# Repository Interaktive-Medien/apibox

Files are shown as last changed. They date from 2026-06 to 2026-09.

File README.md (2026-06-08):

# API Box — ESP32-C6 Sensor-API

**Modul:** Interaktive Medien 3 an der Fachhochschule Graubünden
**Studiengang:** Multimedia Production · 3. Semester
**Board:** Waveshare ESP32-C6-N8

> Eine wasserdichte IoT-Applikation auf dem ESP32-C6, die als **HTTP-API-Endpunkt**
> fungiert. Angeschlossene Sensoren werden in Echtzeit per HTTP GET abgefragt und als
> **JSON** zurückgegeben — bereit zum Einsammeln und Auswerten über einen längeren Zeitraum.

*[Platz für Bilder / GIFs des fertigen Aufbaus]*

---

## Kurzbeschreibung des Projekts

Die **API Box** ist ein kleiner Webserver auf dem ESP32-C6. Sie verbindet sich mit einem
WLAN und stellt für jeden angeschlossenen Sensor einen eigenen API-Endpunkt bereit.
Ein beliebiger Netzwerkteilnehmer (Browser, JavaScript `fetch()`, PHP `cURL`) ruft einen
Endpunkt auf und erhält den aktuellen Messwert als JSON-String:

```
GET http://192.168.0.42/temperatur

{
  "wert": 22.7,
  "einheit": "°C",
  "datentyp": "float",
  "sensor": "SCD41"
}
```

Werte werden **punktuell** abgefragt (kein dauerhaftes Logging auf dem ESP) — gespeichert
und ausgewertet wird auf der Client-/Serverseite.

Findet der ESP kein bekanntes Netzwerk, startet er ein **Captive Portal** (Access Point
`apibox`) mit einem modernen Formular zur Eingabe der WLAN-Zugangsdaten. Ein **SSD1306
OLED** zeigt jederzeit den Status (Suche / verbunden + IP / Portal-Hinweis).

---

## Setup

### Was benötige ich an Infrastruktur?

* **Waveshare ESP32-C6-N8** + USB-C-Kabel
* **Arduino IDE** (2.x) mit installiertem **ESP32 Arduino Core 3.3.x** (Boardverwalter)
* Das Plugin **[arduino-littlefs-upload](https://github.com/earlephilhower/arduino-littlefs-upload)**
  (zum Hochladen der Website-Dateien)
* Breadboard, Jumperkabel, die unten gelisteten Sensoren
* Ein WLAN-Netzwerk (Heim **oder** Schule/eduroam)

### Benötigte Arduino-Libraries

Über **Library Manager** installieren:

| Library | Zweck |
|---|---|
| `Arduino_JSON` (Arduino) | JSON-Antworten erzeugen |
| `Adafruit SSD1306` (+ GFX, + BusIO) | OLED-Display |
| `Sensirion I2C SCD4x` (+ Sensirion Core) | SCD41: Temperatur, Luftfeuchtigkeit, CO2 |
| `BH1750` (Christopher Laws) | Helligkeit |
| `ICM20948_WE` (Wolfgang Ewald) | Lage / 9DOF |
| `HX711 Arduino Library` (Bogdan Necula) | Gewicht |
| `Adafruit BMP280 Library` (+ Adafruit Unified Sensor) | Luftdruck + Höhe |
| `Adafruit VL53L0X` | Distanz |

`WiFi`, `WebServer`, `DNSServer`, `Preferences`, `Wire`, `LittleFS`, `driver/i2s.h`
sind im ESP32-Core bereits enthalten.

### Komponentenplan

```
                         ┌─────────────────────────────┐
        WLAN  ◀────────▶ │   Waveshare ESP32-C6-N8     │
   (Heim / eduroam)      │   ── mc.ino (Webserver) ──  │
                         └──────────────┬──────────────┘
                                        │
         ┌──────────────────────────────┼───────────────────────────────┐
         │ I2C-Bus (GPIO6 SDA / GPIO7 SCL)                               │
         │   ├─ SSD1306 OLED      → display.h        (Statusanzeige)     │
         │   ├─ SCD41             → temperatur.h / luftfeuchtigkeit.h /  │
         │   │                      co2.h            (/temperatur …)     │
         │   ├─ BH1750            → helligkeit.h     (/helligkeit)       │
         │   ├─ ICM-20948         → lage.h           (/lage)            │
         │   ├─ BMP280            → luftdruck.h / hoehe.h (/luftdruck…)  │
         │   └─ VL53L0X           → distanz.h        (/distanz)          │
         │                                                               │
         │ Digital / Analog / I2S                                        │
         │   ├─ SR602  PIR  GPIO4        → bewegung.h    (/bewegung)     │
         │   ├─ GPS14-B     GPIO11       → magnet.h      (/magnet)       │
         │   ├─ MQ-3        GPIO5 (ADC)  → alkohol.h     (/alkohol)      │
         │   ├─ MQ-2        GPIO0 (ADC)  → rauch.h       (/rauch)        │
         │   ├─ INMP441 I2S GPIO2/13/23  → lautstaerke.h (/lautstaerke)  │
         │   ├─ HX711       GPIO21/22    → gewicht.h     (/gewicht)      │
         │   └─ Taster      GPIO20       → captive_portal.h (Portal)     │
         │                                                               │
         │ Webseite (LittleFS): data/index.html + css + js               │
         └───────────────────────────────────────────────────────────────┘
                                        │
        Client: fetch() (JS)  ◀────────┴────────▶  Server: cURL (PHP)
```

### Verkabelung / Pinbelegung

| ESP32-C6 Pin | Komponente | Hinweis |
|---|---|---|
| **GPIO6 (SDA) / GPIO7 (SCL)** | I2C-Bus: SSD1306, SCD41, BH1750, ICM-20948, BMP280, VL53L0X | gemeinsamer Bus |
| GPIO4 | SR602 PIR (Bewegung) | Input |
| GPIO5 | MQ-3 (Alkohol) | Analog/ADC1, VCC **5V** |
| GPIO0 | MQ-2 (Rauch) | Analog/ADC1, VCC **5V** |
| GPIO11 | GPS14-B (Magnet) | INPUT_PULLUP |
| GPIO20 | Taster (Captive Portal) | INPUT_PULLDOWN |
| GPIO2 / GPIO13 / GPIO23 | INMP441 SCK / SD / WS | I2S, L/R → GND |
| **GPIO21 / GPIO22** | HX711 DT / SCK (Waage) | **siehe Warnung unten** |
| 3.3V / 5V / GND | Versorgung | MQ-Sensoren brauchen 5V |

> ⚠️ **Wichtig — HX711 NICHT auf GPIO6/7!**
> Im ursprünglichen Steckplan lag der HX711 (Waage) auf GPIO6/7 — das ist aber der I2C-Bus.
> Der HX711 ist **kein I2C-Gerät** und würde den Bus (Display + 5 Sensoren) stören.
> Deshalb in dieser Applikation auf **GPIO21 (DT) / GPIO22 (SCK)** verlegt. Bitte die Waage
> entsprechend verdrahten.

> 💡 **Zur Frage I2C-Pull-ups (2.2 kΩ auf SDA/SCL nach 3.3V):** Grundsätzlich sinnvoll,
> **aber** die meisten Breakout-Boards (BH1750, BMP280, SCD41, OLED) haben bereits Pull-ups
> onboard. Hängen viele Module am Bus, summieren sich diese parallel und ziehen den Bus zu
> stark. Empfehlung: **ein einziges** Paar 2.2–4.7 kΩ genügt — nicht pro Sensor. Bei kurzen
> Breadboard-Strecken oft ganz verzichtbar. Treten I2C-Aussetzer auf, ist ein Pull-up-Paar
> der erste Versuch.

### Steckplan

Der Fritzing-Steckplan liegt im Repository (`steckplan.png`). Erstellt mit
[Fritzing](https://fritzing.org). Fritzing-Parts für die Lehrveranstaltung:
[Interaktive-Medien / 15_Intro_Projektdoku](https://github.com/Interaktive-Medien/im_physical_computing/tree/main/15_Intro_Projektdoku).

*(Achtung: Im Steckplan liegt der HX711 noch auf GPIO6/7 — in der Software auf GPIO21/22
korrigiert, siehe Warnung oben.)*

### Umgang mit LittleFS (Website hochladen)

Die Website (HTML/CSS/JS) wird **getrennt vom Code** als Datei-Image hochgeladen:

1. Plugin **arduino-littlefs-upload** installieren (siehe Link oben). Video-Tutorial:
   <https://youtu.be/Qw5mQus-WwA>
2. Die Dateien liegen im Ordner **`mc/data/`** (`index.html`, `css/style.css`, `js/script.js`).
3. In der Arduino IDE: `mc.ino` öffnen → **CMD + SHIFT + P** → **„Upload LittleFS to
   Pico/ESP8266/ESP32"**.
4. Dabei wird der komplette `data/`-Ordner auf den ESP gespiegelt. Alte Dateien auf dem ESP
   werden gelöscht — nicht mehr benötigte Dateien müssen also nicht manuell entfernt werden.

### Kalibration (Gewicht & Lautstärke)

Zwei Sensoren brauchen einen **einmalig** zu ermittelnden Kalibrationswert, der persistent
in **Preferences** (Namespace `calib`) gespeichert und beim Start automatisch geladen wird.

**Gewicht (HX711)** — `calibration/gewicht_kalibrieren.ino`
1. Sketch flashen, seriellen Monitor (115200) öffnen.
2. Waage **leer** lassen → Tare (Nullpunkt).
3. Bekanntes Referenzgewicht auflegen (Standard 100 g, im Sketch `REF_WEIGHT_G` anpassbar).
4. `calFactor` wird berechnet und unter `calib / kf_gewicht` gespeichert.

**Lautstärke (INMP441)** — `calibration/lautstaerke_kalibrieren.ino`
1. Sketch flashen, seriellen Monitor öffnen — der **Roh-dB-Wert** wird laufend angezeigt.
2. Gleichzeitig den realen Pegel mit einem Smartphone-dB-Messgerät messen (z. B. App
   „Dezibel X").
3. Den gemessenen realen Wert (z. B. `58`) im Serial Monitor eintippen + Enter.
4. Der **Shift-Offset** (`realDB − db_raw`) wird berechnet und unter `calib / kf_lautst`
   gespeichert.

> Hinweis: Die NVS-Keys heißen aus technischen Gründen kurz `kf_gewicht` / `kf_lautst`
> (NVS-Schlüssel sind auf 15 Zeichen begrenzt). Sie entsprechen den konzeptionellen
> Variablen `kalibrationsfaktor_gewicht` bzw. `kalibrationsfaktor_lautstaerke`.

### Schritt-für-Schritt: Erstinbetriebnahme

1. Repository klonen, Libraries installieren (siehe Tabelle).
2. *(Optional, empfohlen)* Kalibrations-Sketches aus `calibration/` flashen → Faktoren setzen.
3. `mc/data/` per **„Upload LittleFS to ESP"** hochladen.
4. **`mc/mc.ino`** flashen.
5. **Erststart ohne Credentials:** ESP öffnet AP **`apibox`** (offen). Mit dem Handy/Laptop
   verbinden → Setup-Seite öffnet automatisch (Captive Portal) → Reiter **Heimnetzwerk**
   oder **Schulnetzwerk** wählen, Zugangsdaten eingeben, speichern.
6. ESP startet neu und verbindet sich. Das **Display** zeigt `Verbunden mit <SSID>` und die
   **IP-Adresse**. Die Status-LED leuchtet **grün**.
7. Im Browser testen: `http://<IP>/temperatur`, `http://<IP>/` (Dashboard), `http://<IP>/api`
   (Liste aller Endpunkte).
8. Netzwerk später wechseln: **Taster (GPIO20)** drücken → Captive Portal startet erneut.

---

## Technische Details

### Wie reden die Dateien miteinander?

* **`mc.ino`** ist die Zentrale: initialisiert I2C, Display, alle Sensoren und das WLAN,
  registriert die API-Routen und betreibt im `loop()` den Webserver. Jede Sensorlogik ist in
  eine eigene **`.h`-Datei** ausgelagert; `mc.ino` bindet sie per `#include` ein und ruft je
  Endpunkt eine `getXxx()`-Funktion auf (mit Kommentar, in welcher Datei sie steht).
* In der **Arduino IDE** erscheinen alle `.h`-Dateien im `mc/`-Ordner automatisch als **Tabs**
  und werden gemeinsam mit `mc.ino` kompiliert. Die Ordner `tests/`, `calibration/` und
  `examples/` liegen **daneben** (nicht in `mc/`) und werden daher **nicht** mitkompiliert.

### Weg der Daten

```
HTTP GET /temperatur
        │
        ▼
mc.ino  →  server.on("/temperatur")  →  getTemperatur()      [temperatur.h]
                                              │
                                              ▼
                                   readSCD41()  liest I2C-Sensor (gecacht, ≥5 s)
                                              │
                                              ▼
                                   Arduino_JSON baut {wert,einheit,datentyp,sensor}
                                              │
                                              ▼
                                   server.send(200, "application/json", …)
        ◀─────────────────────────────────────┘
   JSON-Antwort an den Client
```

### Besondere Entscheidungen

* **SCD41 wird geteilt:** Ein Sensor liefert Temperatur, Luftfeuchtigkeit **und** CO2.
  `readSCD41()` (in `temperatur.h`) liest alle drei Werte gebündelt und cached sie;
  `luftfeuchtigkeit.h` und `co2.h` greifen auf den Cache zu. Das verhindert mehrfache
  I2C-Zugriffe und Konflikte.
* **BMP280 wird geteilt:** Ein `Adafruit_BMP280`-Objekt in `luftdruck.h` wird von `hoehe.h`
  mitbenutzt (deshalb `luftdruck.h` vor `hoehe.h` einbinden).
* **On-demand:** Werte werden nur bei einer Anfrage gelesen — kein Dauer-Logging.
* **WLAN-Credentials & Kalibrationsfaktoren** liegen persistent in **Preferences** und
  überleben Neustarts/Stromausfall.

### Datenschnittstelle (zwischen WebApp und Physical Computing)

* **Format:** JSON, immer mit den Feldern `wert`, `einheit`, `datentyp`, `sensor`.
* **Transport:** HTTP GET, ein Endpunkt pro Messwert.
* **Client-seitig:** `examples/client_fetch.html` zeigt den Abruf mit `fetch()`.
* **Server-seitig:** `examples/server_proxy.php` zeigt den Abruf mit `curl_init` /
  `curl_setopt` / `curl_exec` / `curl_close` (nützlich als CORS-Proxy und zum Speichern in
  einer Datenbank).

### API-Übersicht

| Endpunkt | Bauteil | `datentyp` | `einheit` | Beispiel `wert` |
|---|---|---|---|---|
| `/temperatur` | SCD41 | float | °C | 22.7 |
| `/luftfeuchtigkeit` | SCD41 | float | % | 48.3 |
| `/co2` | SCD41 | int | ppm | 500 |
| `/bewegung` | SR602 | boolean | bewegung | true |
| `/lautstaerke` | INMP441 | float | dB | 58.4 |
| `/magnet` | GPS14-B | boolean | magnet_erkannt | false |
| `/helligkeit` | BH1750 | float | lx | 423.7 |
| `/alkohol` | MQ-3 | float | mg/L | 0.12 |
| `/lage` | ICM-20948 | object<float,float,float> | ° | {x,y,z} |
| `/gewicht` | HX711 | float | kg | 2.37 |
| `/rauch` | MQ-2 | int | analog_value | 350 |
| `/luftdruck` | BMP280 | float | hPa | 1013.25 |
| `/hoehe` | BMP280 | float | m | 450.2 |
| `/distanz` | VL53L0X | int | mm | 342 |
| `/api` | – | – | – | Liste aller Endpunkte |

---

## Organisation

### Projektstruktur

```
ESP_Sensors/
├── README.md                       ← diese Datei
├── steckplan.png                   ← Fritzing-Steckplan (hier ablegen)
│
├── mc/                             ← HAUPT-SKETCH (dieser Ordner wird kompiliert)
│   ├── mc.ino                     ← Einstieg: WLAN, Webserver, API-Routen, Loop
│   ├── display.h                  ← SSD1306 OLED
│   ├── captive_portal.h           ← AP "apibox", DNS, Setup-Formular, Credentials, Taster
│   ├── temperatur.h               ← SCD41 (gemeinsames readSCD41)
│   ├── luftfeuchtigkeit.h         ← SCD41
│   ├── co2.h                      ← SCD41
│   ├── bewegung.h                 ← SR602 PIR
│   ├── lautstaerke.h              ← INMP441 (+ Kalibrationsfaktor)
│   ├── magnet.h                   ← GPS14-B Reed
│   ├── helligkeit.h               ← BH1750
│   ├── alkohol.h                  ← MQ-3
│   ├── lage.h                     ← ICM-20948
│   ├── gewicht.h                  ← HX711 (+ Kalibrationsfaktor)
│   ├── rauch.h                    ← MQ-2
│   ├── luftdruck.h                ← BMP280
│   ├── hoehe.h                    ← BMP280
│   ├── distanz.h                  ← VL53L0X
│   └── data/                      ← per LittleFS hochladen
│       ├── index.html             ← Dashboard (fetch() aller Endpunkte)
│       ├── css/style.css
│       └── js/script.js
│
├── tests/                         ← getestete Original-Demo-Codes je Sensor/Technik
│   ├── temperatur.ino  luftfeuchtigkeit.ino  co2.ino  bewegung.ino
│   ├── lautstaerke.ino  magnet.ino  helligkeit.ino  alkohol.ino  lage.ino
│   ├── gewicht.ino  rauch.ino  luftdruck.ino  hoehe.ino  distanz.ino
│   ├── oled_display.ino  button.ino  preferences.ino
│   └── captive_portal.ino  littlefs_webserver.ino
│
├── calibration/                   ← einmalige Kalibrationsprogramme
│   ├── gewicht_kalibrieren.ino
│   └── lautstaerke_kalibrieren.ino
│
└── examples/                      ← API-Abruf von aussen
    ├── client_fetch.html          ← client-seitig (JavaScript fetch)
    └── server_proxy.php           ← server-seitig (PHP cURL)
```

Jede Code-Datei hat im **Kopfbereich** eine kurze Zusammenfassung (Zweck, benötigte Library,
Verkabelung). `mc.ino` enthält zusätzlich den vollständigen Pinplan.

---

## Known Bugs / Hinweise

* **MQ-3 / MQ-2 & ADC-Spannung:** Beide Sensoren laufen mit **5V** am Heizer; ihr Analogausgang
  (AO) kann über 3.3V steigen und den ESP32-Eingang sättigen/belasten. Für saubere Werte einen
  **Spannungsteiler** (z. B. 2×10 kΩ) vor den ADC-Pin setzen. Beide Sensoren liegen auf
  **ADC1** (ADC2 ist bei aktivem WLAN nicht nutzbar).
* **MQ-Aufwärmzeit:** MQ-3/MQ-2 brauchen 1–5 Minuten Vorheizen für stabile Werte; direkt nach
  dem Start sind die Werte zu hoch.
* **Alkohol in mg/L** ist nur eine **grobe lineare Näherung** aus dem Rohwert — ohne echte
  Gas-Kalibration nicht messtechnisch belastbar.
* **SCD41-Intervall:** Der Sensor misst intern ca. alle 5 s. Sehr schnelle aufeinanderfolgende
  Abfragen liefern denselben (gecachten) Wert.
* **ICM-20948 `autoOffsets()`** läuft beim Start — das Board währenddessen **flach und ruhig**
  halten, sonst sind die Winkel verschoben.
* **HX711-Verdrahtung:** muss auf GPIO21/22 liegen (nicht 6/7), sonst kollidiert die Waage mit
  dem I2C-Bus (siehe Warnung oben).
* **CORS:** Der ESP setzt keinen `Access-Control-Allow-Origin`-Header. Für Cross-Origin-Zugriffe
  aus dem Browser entweder die Seite über die API Box selbst ausliefern oder den
  PHP-Proxy (`server_proxy.php`) verwenden.
* **Captive Portal offen:** Der Access Point `apibox` ist absichtlich ohne Passwort — nur für
  die Einrichtung gedacht.

### Was könnte noch verbessert werden?

* Echte Kalibrationskurven für die Gassensoren (MQ-3/MQ-2).
* Optionaler `Access-Control-Allow-Origin: *`-Header für direkten Browser-Zugriff.
* Mittelwertbildung/Glättung pro Endpunkt konfigurierbar machen.
* Absicherung der API (Token) für den Produktivbetrieb.

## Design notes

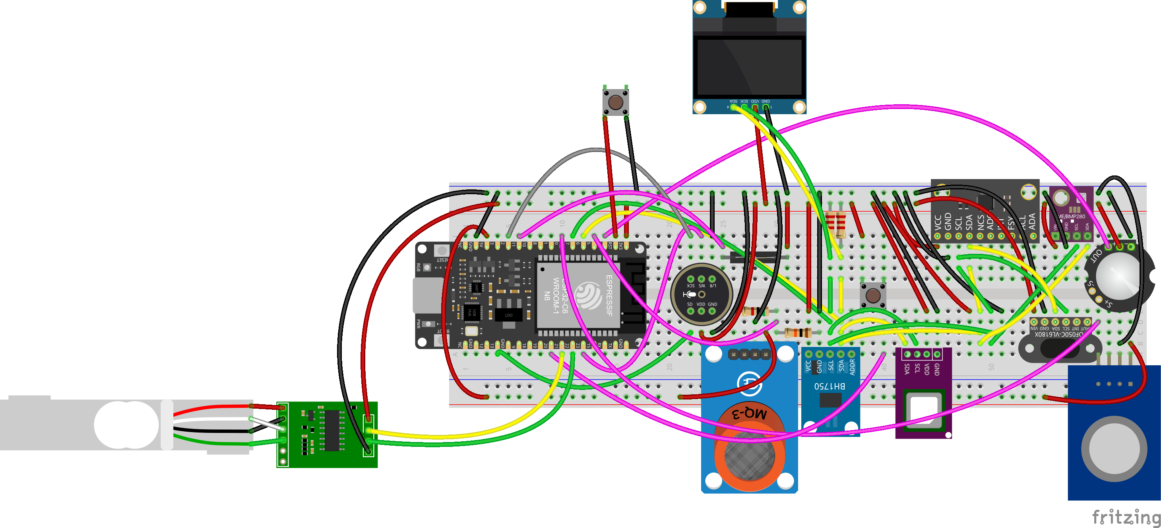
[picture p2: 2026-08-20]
mc/Steckplan.png

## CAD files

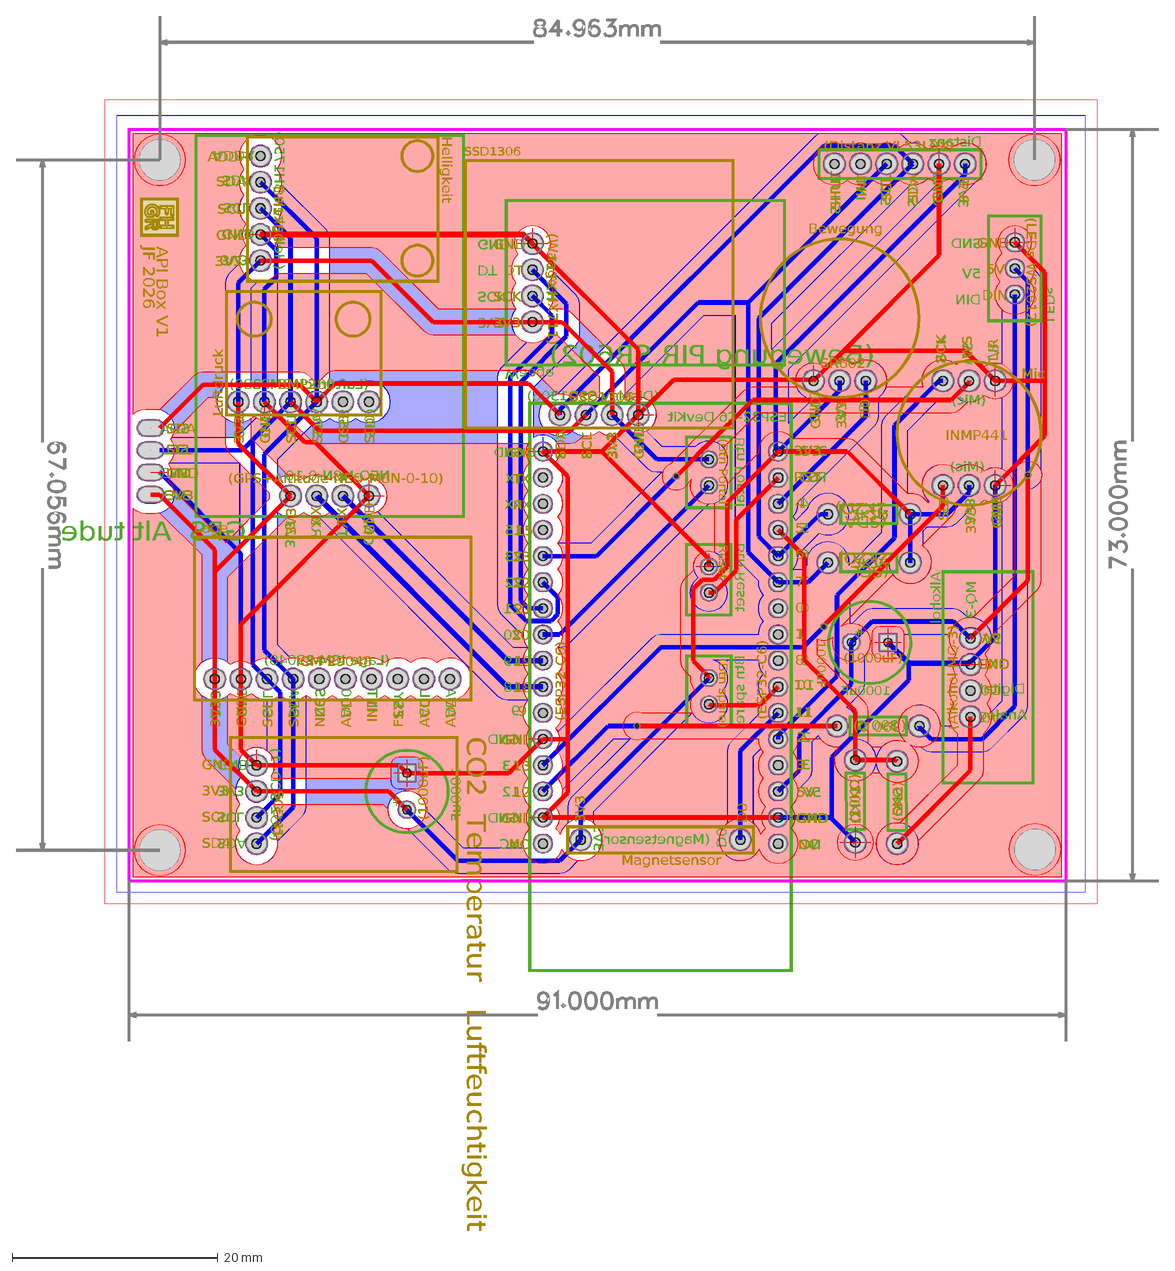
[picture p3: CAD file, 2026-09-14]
mc/PCB/DXF_PCB_2026-09-03_AutoCAD2007.dxf
390 Ω
2k2Ω
+
DIN
5V
GND
LEDs
1000uF
Digital
Analog
MQ-3
Alkohol
HX711
Waage
3V3
SCK
DT
SHUT
INT
SCL
SDA
Distanz
NEO-M8N-0-10
GPS Altitude
TX
RX
ESP32-C6 DevKit
9
19
13
12
18
15
21
23
20
22
NC
RST
10
11
6
8
5
0
2
3
7
4
1
(Display SSD1306)
Btn spare
Btn Reset
Btn Portal
10KΩ
ADDR
(Helligkeit BH1750)
SD
WS
L/R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

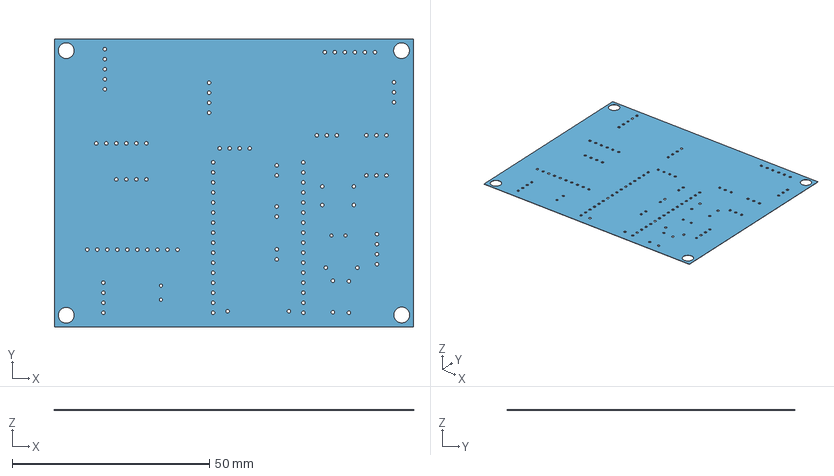
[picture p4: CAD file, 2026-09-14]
mc/PCB/3D_PCB_2026-09-03.step
91.0 x 73.0 x 0.09 mm
Board~ud65
TopCopper~ud65
BottomCopper~ud65
TopSilkscreen~ud65
BottomSilkscreen~ud65
TopFpcStiffener~ud65
BottomFpcStiffener~ud65

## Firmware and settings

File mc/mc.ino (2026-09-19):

/******************************************************************************
 *  mc.ino — Sensorbox Hauptprogramm
 *
 *  Beschreibung:
 *  Der ESP32-C6 verbindet sich mit einem WLAN-Netzwerk und sendet die Messwerte
 *der angeschlossenen Sensoren in regelmässigen zeitlichenAbständen als
 *JSON-String an einen zentralen Server. Ist kein bekanntes Netzwerk verfügbar,
 *startet ein Captive Portal (Access Point z.B. "sensorbox1"), ueber das
 *WLAN-Credentials eingegeben werden koennen.
 *
 *  Board: Waveshare ESP32-C6-N8
 *  Die Logik der einzelnen Sensoren, Libraries und Wiring sind in .h-Dateien
 *ausgelagert. Bei I2C-Sensoren ist der I2C-Bus auf GPIO6 (SDA) und GPIO7 (SCL)
 *gelegt.
 *
 *  I2C Pull-Up: Ein Paar 2.2kOhm an SDA und SCL nach 3.3V
 * Initial müssen in Preferences der Lautstärkesensor INMP441
 *(../calibration/lautstaerke/01_calib.ino) und die Waage (über HX711 ->
 *../calibration/gewicht/01_calib.ino) vorbereitet und dann gespeichert werden.
 * Ebenfalls muss die box-id in Preferences (Namespace "sensorbox", Key "boxid")
 *gespeichert werden, damit das Captive Portal den richtigen Namen bekommt und
 *die Werte i die richtige DB-Tabelle gespeichert werden
 *(../calibration/box_id_speichern.ino).
 *
 * Im Captive Portal Modus hostet der ESP32-C6 einen Webserver, der die
 *HTML/CSS/JS-Dateien aus dem LittleFS-Dateisystem bereitstellt. Die Dateien
 *können  mit der Arduino IDE hochgeladen werden. Der ESP zeigt dann die
 *Konfigurations-Website an, die im Verzeichnis data liegt (html, css, js). Hier
 *können die Credentials des WLAN Netzwerks mit Internet hineterlegt werden, mit
 *dem sich der ESP32-C6 verbinden soll. Am Gerät befinden sich 2 Buttons:
 * - Reset (Neustart) und
 * - Captive Portal (hier wird erstellt der ESP ein Netzwerk, mit dem sich der
 *Benutzer verbinden kann, um die WLAN-Credentials zu hinterlegen). Wenn fertig,
 *Reset drücken.

 * Falls Programm zu gross für Compiler: Wähle Tools > Partition Scheme > Huge
 APP (3MB No OTA/1MB SPIFFS)
 *****************************************************************************/

#include "FS.h"
#include "LittleFS.h"
#include <Arduino_JSON.h>
#include <HTTPClient.h>
#include <Wire.h>

// ======================== Pin-Definitionen ========================

#define I2C_SDA 6
#define I2C_SCL 7
#define PIN_BUTTON_PORTAL 20
#define PIN_BUTTON_DISPLAY 10
#define PIN_LED BUILTIN_LED

int prevTimestamp = 0;
int intervall_ms = 15000; // 15s -  Mess-Intervalle
int boxid = 0;
float temp_offset = 0.0;
JSONVar latestData;

#include "display.h" // SSD1306 OLED Display
#include "wlan.h" // WLAN Verbindung & Captive Portal (definiert server, preferences etc.)

////////////////////////// Sensor-Header einbinden

#include "alkohol.h"                         // MQ-3 Alkoholsensor
#include "bewegung.h"                        // SR602 PIR
#include "co2_temperatur_luftfeuchtigkeit.h" // SCD41 CO2, Temperatur, Luftfeuchtigkeit
#include "distanz.h"                         // VL53L0X Distanz
#include "gewicht.h"                         // HX711 Waage
#include "gps.h"                             // NEO8M
#include "helligkeit.h"                      // BH1750 Lichtsensor
#include "lage.h"                            // ICM-20948 9DOF
#include "lautstaerke.h"                     // INMP441 Mikrofon
#include "luftdruck.h"                       // BMP280 Luftdruck
#include "magnet.h"                          // GPS14-B Magnetsensor

////////////////////////// LittleFS Datei-Handler

bool handleFileRead(
    String path) // wird aufgerufen in wlan.h: Website-Dateien für Captive
                 // Portal aus LittleFS bereitstellen
{
  if (path.endsWith("/"))
    path += "index.html";

  String contentType = "text/plain";
  if (path.endsWith(".html"))
    contentType = "text/html";
  else if (path.endsWith(".css"))
    contentType = "text/css";
  else if (path.endsWith(".js"))
    contentType = "application/javascript";
  else if (path.endsWith(".ico"))
    contentType = "image/x-icon";
  else if (path.endsWith(".json"))
    contentType = "application/json";

  if (LittleFS.exists(path)) {
    File file = LittleFS.open(path, "r");
    server.streamFile(file, contentType);
    file.close();
    return true;
  }
  return false;
}

void setup() {
  Serial.begin(115200);

  pinMode(PIN_LED, OUTPUT);
  rgbLedWrite(PIN_LED, 0, 255, 0); // Rot (keine WLAN Verbindung)

  preferences.begin("sensorbox", true);
  boxid = preferences.getInt("boxid", 0);
  int intervall_s = preferences.getInt("intervall_s", 15);
  intervall_ms = intervall_s * 1000;
  temp_offset = preferences.getFloat("temp_offset", 0.0);
  float waage_cal = preferences.getFloat("waage_cal", 1.0);
  float dboffset = preferences.getFloat("dboffset", 120.0);
  preferences.end();

  Serial.println("\n--- Gelesene Einstellungen (Preferences) ---");
  Serial.printf("Box ID: %d\n", boxid);
  Serial.printf("Messintervall: %d Sekunden\n", intervall_s);
  Serial.printf("Temperatur-Offset: %.1f °C\n", temp_offset);
  Serial.printf("Gewicht-Faktor: %.4f\n", waage_cal);
  Serial.printf("Mikrofon-Offset: %.1f dB\n", dboffset);
  Serial.println("--------------------------------------------\n");

  Wire.begin(I2C_SDA, I2C_SCL);
  setupDisplay();                     // in display.h
  displayText("Starte Sensorbox..."); // in display.h

  if (!LittleFS.begin(true)) {
    Serial.println("LittleFS Mount fehlgeschlagen!");
    displayText("LittleFS Fehler!"); // in display.h
  }

  Serial.println("\n--------\nInitialisiere Sensoren...");
  displayText("Sensoren\ninitialisieren..."); // NEW
  setupAlkohol();                             // in alkohol.h
  setupBewegung();                            // in bewegung.h
  setupCo2_Temperatur_Luftfeuchtigkeit(); // co2_temperatur_luftfeuchtigkeit.h
  setupDistanz();                         // in distanz.h
  setupGewicht();                         // in gewicht.h
  setupGPS();                             // in gps.h
  setupHelligkeit();                      // in helligkeit.h
  setupLage();                            // in lage.h
  setupLautstaerke();                     // in lautstaerke.h
  setupLuftdruck();                       // in luftdruck.h
  setupMagnet();                          // in magnet.h
  Serial.println("\n-------- Initialisierung der Sensoren abgeschlossen...");

  pinMode(PIN_BUTTON_DISPLAY, INPUT_PULLDOWN);
  setupPortalButton(); // in wlan.h
  setupWLAN();         // in wlan.h
  Serial.println("\n-------- Setup abgeschlossen...");
  Serial.println("\n-------- Sensorwerte alle " + String(intervall_ms) +
                 " ms abfragen...");
}

void loop() {
  JSONVar dataObject;

  maintainWiFiConnection(); // in wlan.h
  checkDisplayButton();     // in display.h

  if (millis() < prevTimestamp + intervall_ms)
    return;
  prevTimestamp = millis();

  float alkohol = getAlkohol(); // in alkohol.h
  Serial.printf("Alkohol: %.2f mg/L\n", alkohol);
  dataObject["alkohol"] = alkohol;

  int bewegung = getBewegung(); // in bewegung.h
  Serial.printf("Bewegung: %d\n", bewegung);
  dataObject["bewegung"] = bewegung;

  getCo2_Temperatur_Luftfeuchtigkeit(); // in co2_temperatur_luftfeuchtigkeit.h
  Serial.printf("CO2: %d ppm\n", co2);
  Serial.printf("Temperatur: %.2f °C\n", temperature);
  Serial.printf("Luftfeuchtigkeit: %.2f %%\n", humidity);
  dataObject["co2"] = co2;
  dataObject["temperatur"] = temperature;
  dataObject["luftfeuchtigkeit"] = humidity;

  int distanz = getDistanz(); // in distanz.h
  Serial.printf("Distanz: %d\n", distanz);
  dataObject["distanz"] = distanz;

  float gewicht = getGewicht(); // in gewicht.h
  Serial.printf("Gewicht: %.2f g\n", gewicht);
  dataObject["gewicht"] = gewicht;

  getGPS(); // in gps.h
  Serial.printf("Latitude: %.6f°\n", latitude);
  Serial.printf("Longitude: %.6f°\n", longitude);
  Serial.printf("Altitude: %.2f m\n", altitude);
  Serial.printf("Satelliten: %d\n", satellites);
  Serial.printf("timeString: %s\n", timeString.c_str());
  dataObject["latitude"] = latitude;
  dataObject["longitude"] = longitude;
  dataObject["altitude"] = altitude;
  dataObject["gps_num_satellites"] = satellites;
  dataObject["gps_time"] = timeString;

  float helligkeit = getHelligkeit(); // in helligkeit.h
  Serial.printf("Helligkeit: %.2f lux\n", helligkeit);
  dataObject["helligkeit"] = helligkeit;

  getLage(); // in lage.h
  Serial.printf("lage_x: %.2f\n", lage_x);
  Serial.printf("lage_y: %.2f\n", lage_y);
  dataObject["lage_x"] = lage_x;
  dataObject["lage_y"] = lage_y;

  float lautstaerke = getLautstaerke(); // in lautstaerke.h
  Serial.printf("Lautstärke: %.2f dB\n", lautstaerke);
  dataObject["lautstaerke"] = lautstaerke;

  float luftdruck = getLuftdruck(); // in luftdruck.h
  Serial.printf("Luftdruck: %.2f hPa\n", luftdruck);
  dataObject["luftdruck"] = luftdruck;

  int magnet = getMagnet(); // in magnet.h
  Serial.printf("Magnet: %d\n", magnet);
  dataObject["magnet"] = magnet;

  ////////////////////////// Sensorwerte in JSON-String codieren");
  dataObject["boxid"] = boxid;
  latestData = dataObject;
  renderCurrentPage();

  String jsonString = JSON.stringify(dataObject);
  // Serial.println(jsonString);

  ////////////////////////// JSON string per HTTP POST Request an den Server
  /// schicken (server2db.php)

  String serverURL = "https://sensorbox.fiessling.ch/api/set.php";

  if (WiFi.status() == WL_CONNECTED) { // Überprüfen, ob Wi-Fi verbunden ist
    // HTTP Verbindung starten und POST-Anfrage senden
    HTTPClient http;
    http.begin(serverURL);
    http.addHeader("Content-Type", "application/json");
    int httpResponseCode = http.POST(jsonString);

    // Prüfen der Antwort vom Server
    if (httpResponseCode > 0) {
      String response = http.getString();
      Serial.printf("HTTP Response code: %d\n", httpResponseCode);
      Serial.println("Response: " + response);
    } else {
      Serial.printf("Error on sending POST: %d\n", httpResponseCode);
    }

    http.end();
    Serial.println("\n-----------------------------\n");
  } else {
    Serial.println("WiFi Disconnected");
  }
}

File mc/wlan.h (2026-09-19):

/**********************************************************************************************
 *  wlan.h
 *  WLAN-Verbindung + Captive Portal + Reconnect-Logik + persistente Credentials
 *  Fasst alle WLAN-Funktionen zusammen.
 **********************************************************************************************/

#ifndef WLAN_H
#define WLAN_H

#include "esp_eap_client.h" // WPA2-Enterprise API
#include <DNSServer.h>
#include <Preferences.h>
#include <WebServer.h>
#include <WiFi.h>

// ---------------------------------------------------------------------------
// Globale WLAN-Objekte und Variablen
// ---------------------------------------------------------------------------
WebServer server(80);
DNSServer dnsServer;
Preferences preferences;

const byte DNS_PORT = 53;
bool apMode = false;
bool wlanConnected = false;
bool portalRoutesRegistered = false;

#define PIN_LED BUILTIN_LED

// Forward Declarations für Funktionen aus anderen Headern/Dateien
void displayText(String text);    // in display.h
bool handleFileRead(String path); // in mc.ino
// void setupAPIRoutes();            // in mc.ino

// ---------------------------------------------------------------------------
// Taster (GPIO20) zum manuellen Start des Captive Portals
// ---------------------------------------------------------------------------
// aufgerufen in mc.ino
void setupPortalButton() { pinMode(PIN_BUTTON_PORTAL, INPUT_PULLDOWN); }

bool checkPortalButton() {
  static int prevState = LOW;
  int state = digitalRead(PIN_BUTTON_PORTAL);
  bool pressed = (state == HIGH && prevState == LOW);
  prevState = state;
  return pressed;
}

// ---------------------------------------------------------------------------
// Captive Portal Handler & Funktionen
// ---------------------------------------------------------------------------
void handlePortalRoot() {
  if (LittleFS.exists("/index.html")) {
    File file = LittleFS.open("/index.html", "r");
    server.streamFile(file, "text/html");
    file.close();
  } else {
    server.send(404, "text/plain", "Setup-Seite nicht in LittleFS gefunden.");
  }
}

void handlePortalSave() {
  String mode = server.hasArg("mode") ? server.arg("mode") : "home";

  if (mode == "advanced") {
    preferences.begin("sensorbox", false);

    if (server.hasArg("boxid") && server.arg("boxid").length() > 0) {
      preferences.putInt("boxid", server.arg("boxid").toInt());
    }
    if (server.hasArg("temp_offset") &&
        server.arg("temp_offset").length() > 0) {
      preferences.putFloat("temp_offset", server.arg("temp_offset").toFloat());
    }
    if (server.hasArg("intervall_s") &&
        server.arg("intervall_s").length() > 0) {
      preferences.putInt("intervall_s", server.arg("intervall_s").toInt());
    }
    if (server.hasArg("waage_cal") &&
        server.arg("waage_cal").length() > 0) {
      preferences.putFloat("waage_cal",
                           server.arg("waage_cal").toFloat());
    }
    if (server.hasArg("dboffset") && server.arg("dboffset").length() > 0) {
      preferences.putFloat("dboffset", server.arg("dboffset").toFloat());
    }

    preferences.end();

    String resp = "<!DOCTYPE html><html><head><meta charset='utf-8'>";
    resp +=
        "<meta name='viewport' content='width=device-width, initial-scale=1'>";
    resp += "<style>body{font-family:sans-serif;background:#2a5298;color:#fff;";
    resp += "display:flex;align-items:center;justify-content:center;height:"
            "100vh;text-align:center}</style>";
    resp += "</head><body><div><h2>Erweiterte Einstellungen gespeichert!</h2>";
    resp += "<p>Die Sensorbox startet neu...</p></div></body></html>";
    server.send(200, "text/html", resp);

    Serial.println("Erweiterte Einstellungen gespeichert. Neustart in 2s...");
    delay(2000);
    ESP.restart();
    return;
  }

  String ssid =
      server.hasArg("ssid_privat")
          ? server.arg("ssid_privat")
          : (server.hasArg("ssid_schule") ? server.arg("ssid_schule") : "");
  String pass =
      server.hasArg("pass_privat")
          ? server.arg("pass_privat")
          : (server.hasArg("pass_schule") ? server.arg("pass_schule") : "");
  String user = server.hasArg("user_schule") ? server.arg("user_schule") : "";

  // Falls generische Namen verwendet werden (Fallback)
  if (ssid == "" && server.hasArg("ssid"))
    ssid = server.arg("ssid");
  if (pass == "" && server.hasArg("pass"))
    pass = server.arg("pass");
  if (user == "" && server.hasArg("user"))
    user = server.arg("user");

  preferences.begin("wifi", false);
  preferences.putString("mode", mode);

  if (mode == "school") {
    preferences.putString("ssid_schule", ssid);
    preferences.putString("user_schule", user);
    preferences.putString("pass_schule", pass);
  } else {
    preferences.putString("ssid_privat", ssid);
    preferences.putString("pass_privat", pass);
  }
  preferences.end();

  String resp = "<!DOCTYPE html><html><head><meta charset='utf-8'>";
  resp +=
      "<meta name='viewport' content='width=device-width, initial-scale=1'>";
  resp += "<style>body{font-family:sans-serif;background:#2a5298;color:#fff;";
  resp += "display:flex;align-items:center;justify-content:center;height:100vh;"
          "text-align:center}</style>";
  resp += "</head><body><div><h2>Gespeichert!</h2>";
  resp += "<p>SSID: " + ssid + "</p>";
  resp += "<p>Die Sensorbox startet neu und verbindet "
          "sich...</p></div></body></html>";
  server.send(200, "text/html", resp);

  Serial.println("Credentials gespeichert. Neustart in 2s...");
  delay(2000);
  ESP.restart();
}

void startCaptivePortal() {
  Serial.println("\n-----------------------------\nStarte captive WLAN...");
  WiFi.mode(WIFI_AP);

  preferences.begin("sensorbox", true);
  int boxid = preferences.getInt("boxid", 0);
  preferences.end();
  String ssid = "sensorbox" + String(boxid);
  WiFi.softAP(ssid);

  IPAddress apIP = WiFi.softAPIP();
  dnsServer.start(DNS_PORT, "*", apIP);

  if (!portalRoutesRegistered) {
    server.on("/", HTTP_GET, handlePortalRoot);
    server.on("/save", HTTP_POST, handlePortalSave);
    server.onNotFound([]() {
      if (!handleFileRead(server.uri())) { // in mc.ino
        handlePortalRoot();
      }
    });
    portalRoutesRegistered = true;
  }
  server.begin();

  String info = "AP Modus\nIP Adresse:\n" + WiFi.softAPIP().toString() +
                "\nDNS Adresse:\n" + WiFi.softAPIP().toString();
  displayText(info); // in display.h
  Serial.printf("AP Modus gestartet. AP IP: %s, DNS: %s\n",
                WiFi.softAPIP().toString().c_str(),
                WiFi.softAPIP().toString().c_str());
}
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

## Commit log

2026-06-08 erstes Ergebnis nach Claude Prompt
    [Steckplan.fzz]
2026-06-12 esp merkt sich nun WLAN
    [Steckplan.fzz]
2026-08-11 first step in after long summer break
    [Steckplan.fzz, Steckplan_Spannungsteiler.fzz]
2026-08-20 API added
    [Steckplan.fzz, Steckplan_Spannungsteiler.fzz]
2026-08-22 Mic und Waage
2026-08-22 GPS und set.php
2026-08-22 PIR sensor added
    [Steckplan.fzz]
2026-08-22 co2 temperatrur luftfeuchtigkeit
2026-08-22 neues GPS Example File
    [Steckplan.fzz]
2026-08-22 diverse Sensoren angepasst
2026-08-23 Lage, Lautstärke, Magnet, get und set korrigiert
    [lautstaerke.h, magnet.ino, mc.ino]
2026-09-14 PCB files
    [3D_PCB_2026-09-03.step, DXF_PCB_2026-09-03_AutoCAD2007.dxf, Steckplan.fzz]
2026-09-17 nur noch 1 Ta elle für alle Sensorboxen, Testprogramm auf HTML/CSS/JS-Basis
    [mic.fzz]
